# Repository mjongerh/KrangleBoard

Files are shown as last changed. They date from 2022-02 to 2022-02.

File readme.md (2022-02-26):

# Krangle keyboard, a keyboard with way too many buttons
Originally I wanted a keyboard with some additional keys for the purpose of shortcuts in games. 
Then I got inspired by the SpaceCadet and the hyper7 and wanted more buttons, for shortcuts, macros and snippets in coding. 
Unfortunately I couldn't get a keyboard that would suffice my greed, so instead I made my own!
With no experience in building keyboards or 3D-modeling or 3D-printing, I thought I would be a perfect fit for this project.

A lot of insipration was taken from [this](https://github.com/jurassic73/split89/blob/main/readme.md#prepping-the-diodes) example.
It contains a great description of many steps of the assembly process.
I highly recommend to read through it if one intends to builds this or any other 3D-printed handwired keyboard.

A little soundtest for the nerds: https://youtu.be/8HYNmcfg844

## Layout
For the layout I went with a lot of extra buttons for programming and gaming.
Further explaination and information in the [layout](./Layout) section

## Hardware
### 3D modeling the case
In the [STL files](./STLfiles) one can find the stl files for all the parts used.
It was intended to be printed on a creality CR-20, hence the maximum size is 220mmx220mm.
It is definitely not perfect as it was made in SketchUp by a noob.
I would not recommend to us it as a template, but it works as-is and might be helpful as inspiration.
Potential improvements are discussed in the [STL](./STLfiles) section.

### Wiring
Initially the plan was to use 2 microcontrollers, considering the amount of buttons.
However, this has proven to be more difficult than expected.
So instead, I was able to fish a teensy2.0++ from the past and wired everything on a single controller.
In this case it uses the traditional method for wire mapping. (PIN map found in [software](./Software))
Some of the macro wiring does not make sense in this setup, but it was a leftover from a previous attempt.
Considering the amount of space in the keyboard, it should be fine for anyone.
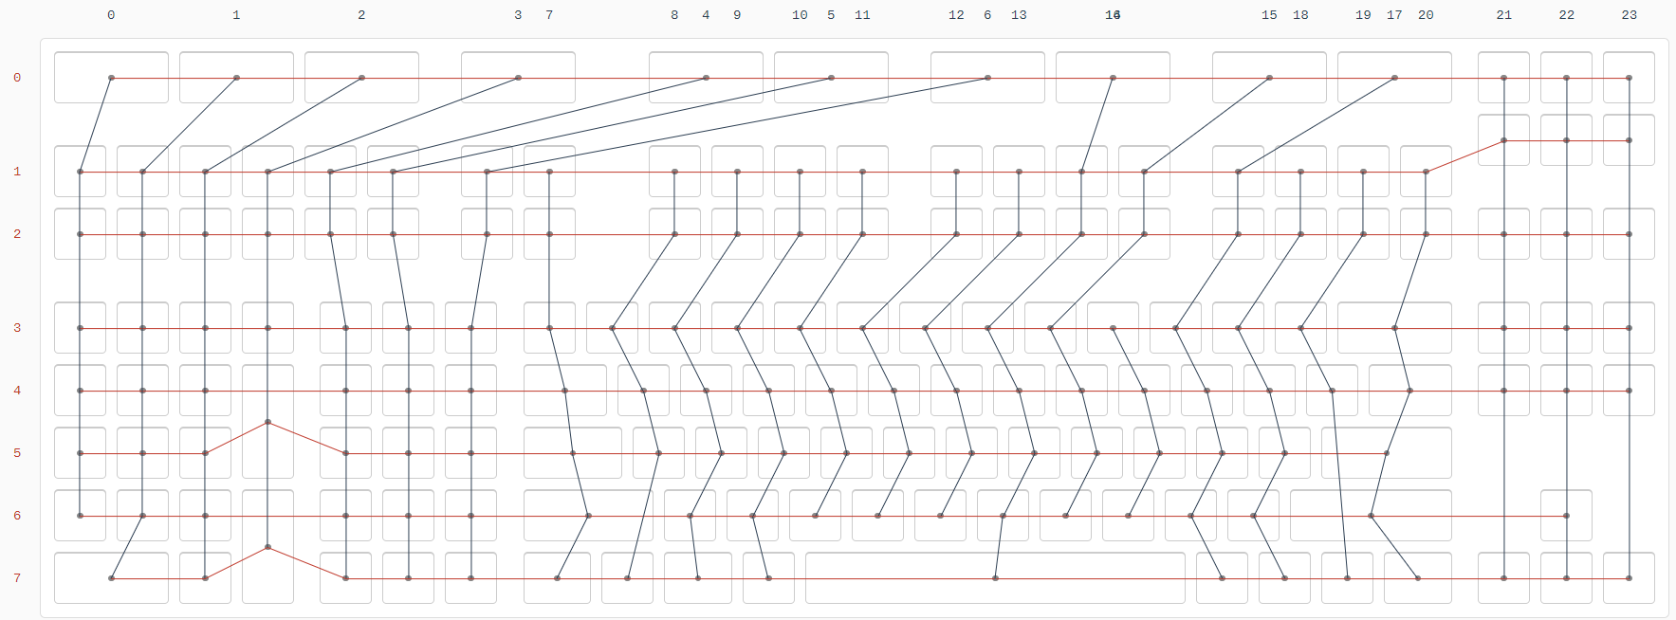
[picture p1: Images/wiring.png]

Note that column 14 is the part that contains only 4 keys in the main part of the board.

Many great tips and tricks can be found externally, for example in [this](https://github.com/jurassic73/split89/blob/main/readme.md#prepping-the-diodes) repo of another 3D printed board.
Out of enthousiasm I designed and 3D-printed a little tool to be used as guidance to bend the pins of the diodes.

### LED circuitry
As the power output of the PINS on any microcontroller are very limited, I used a seperate 5V source for the main set of LEDs.
I cut of one ends of a USB cable and stripped the internal wires.
Only the red(+) and black(-) ones a relevant, so the data wires can be cut off as well.

A typical mothed would be to solder a resistor to each LED and then connect them in parrallel.
This would enable to control each LED individually, which is not on my list of desires and would complicate the connections with the (additional) microcontroller.
However, I am not aware of another benefit of this, apart from a potential short-circuit if one LED somehow breaks.
So I choose to connect all LEDs in parallel with a resistor in series to limit the current.
All negative poles can be soldered in a row and the positive poles likewise.

By connecting these rows together, one ends up with a single point that acts a connection for the negative poles of all LEDs and one for the positive poles.
To control the current to an appropriate level I used ohms law (R=U/I) to calculate a required resistance.
With a maximum of 2mA per LED (obtained experimentally), this would lead to a load resistor of ~15Ω.

To control the current (and therefore the brightness) through the LEDs, I used a MOSFET as 'electronic switch'.
Additionally, two resistors are required as pull-up and pull-down resistor to stabalize the voltage.
This image shows an example setup for the circuit.
Where G,D ans S are the Gate Drain and Source pins of the MOSFET.
PIN indicates the connection to the controlling pin of microcontroller. (PIN map found in [software](./Software))
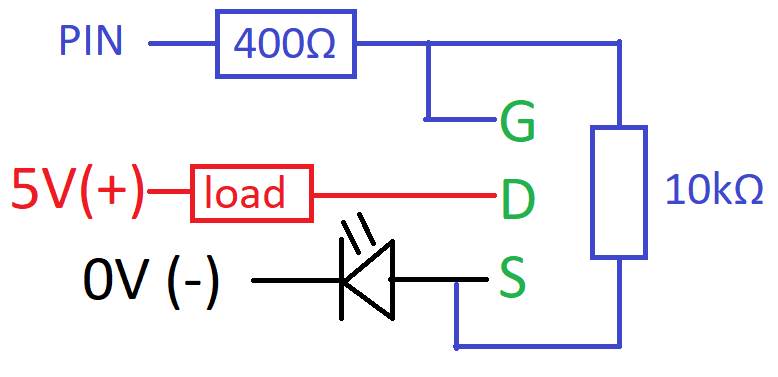
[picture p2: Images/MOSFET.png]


The MOSFET and resistors are placed on the bracket, there is intentionally left some space for this.

The indicator LEDs can be connected directly to the microcontroller, since a single LED don't draw too much current.
This means that a load resistor (2500Ω) should be placed between the microcontroller and the positive end of the LED.
The negative pole of the LED can be connected to the great negative row of the main set of LEDs.
Alternatively it can be connected to the ground pin on the microcontroller.

## Assembly
This section will just show some of the progression of my build.
As a bonus, one will notice how this keyboard got its name.

After putting all the main switchplates and case parts together and pressing all switches in place.
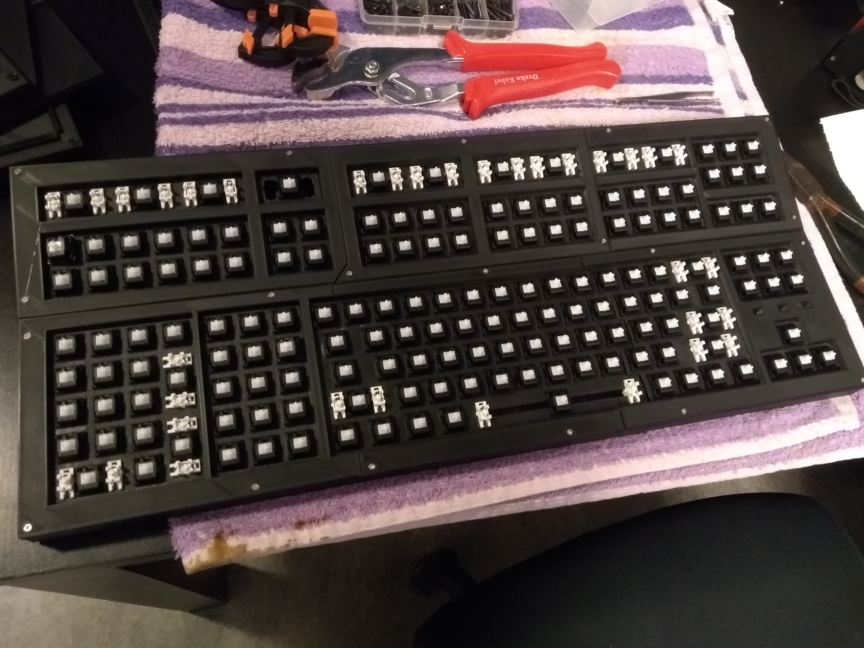
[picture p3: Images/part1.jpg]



Closeup of the wiring and my lackluster soldering skills. 
The bare wires are the pins of the diodes and function as the rows.
The colored wires connect the other pins of the switches and make up the columns.
White and black wires are the + and - of the LEDs.
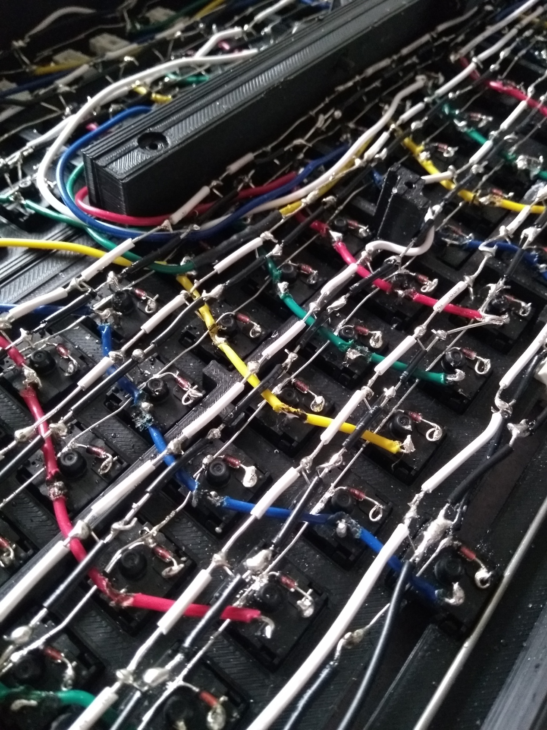
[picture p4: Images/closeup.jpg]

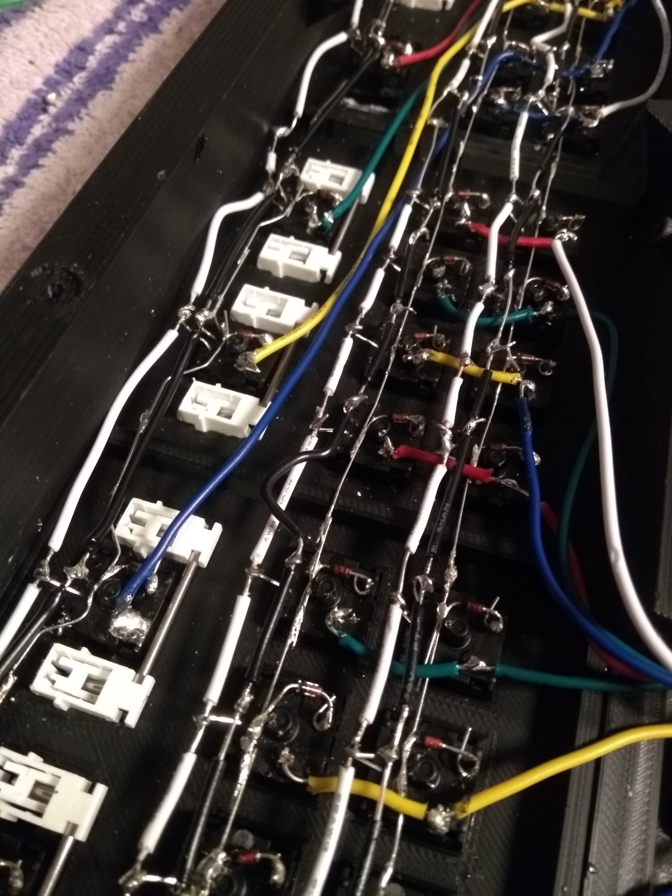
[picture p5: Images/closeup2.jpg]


After connecting the LEDs and testing them.
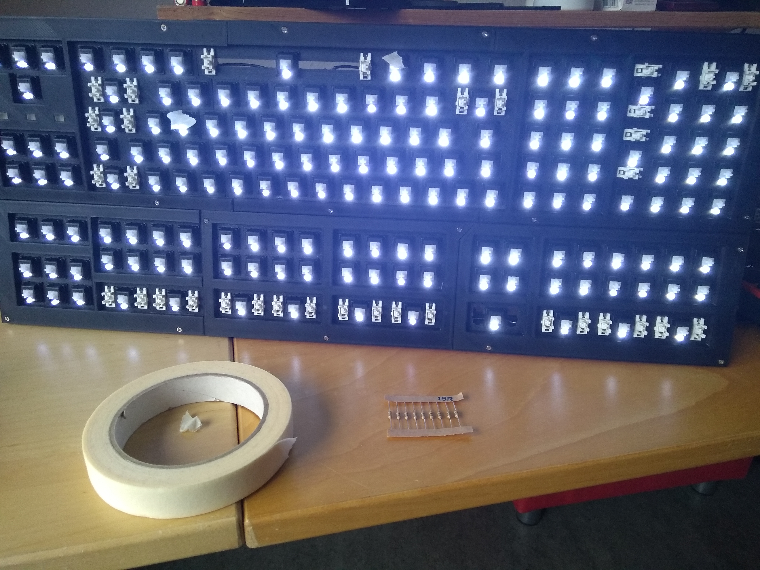
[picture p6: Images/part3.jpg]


Closeup of how the MOSFET is installed
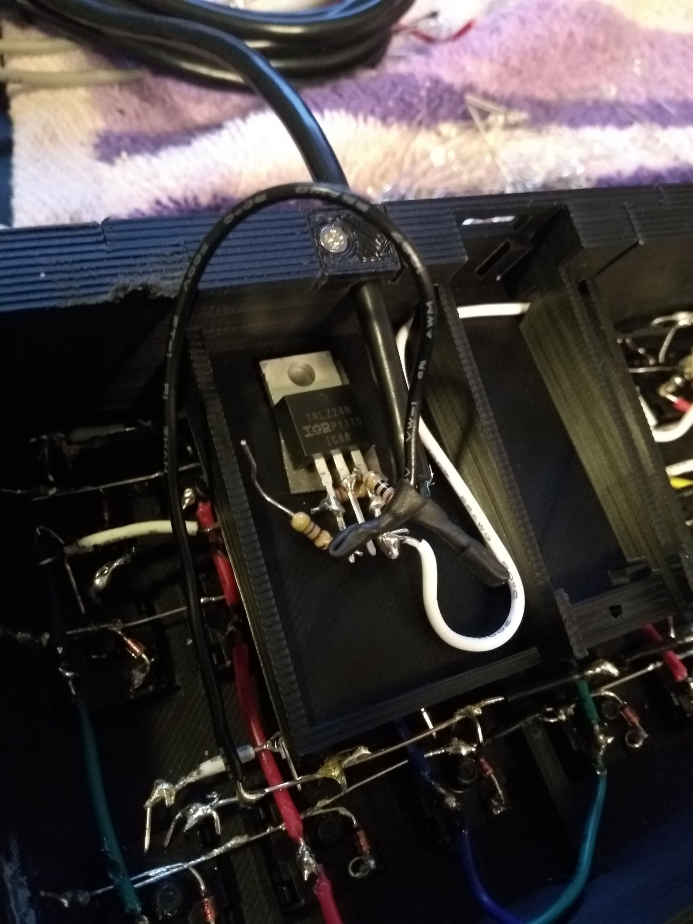
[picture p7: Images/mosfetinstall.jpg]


The beauty in all its glory.
On a daily basis I pray for the wires or one of the connection not to break.
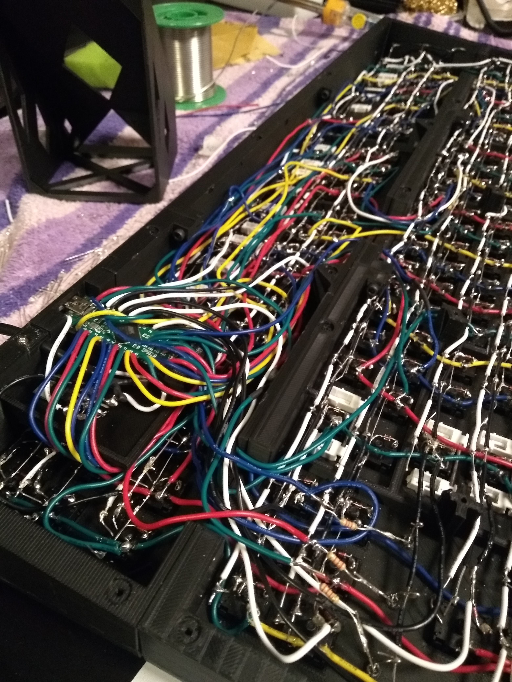
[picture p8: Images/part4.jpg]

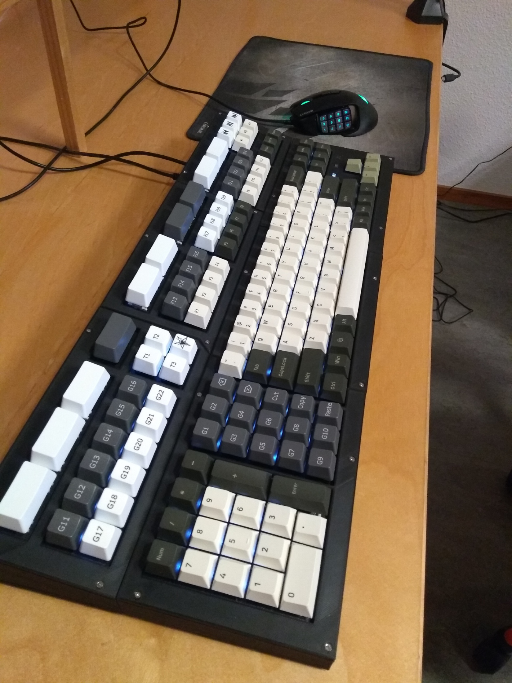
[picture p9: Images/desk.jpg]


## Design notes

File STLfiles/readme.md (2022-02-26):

# STL files
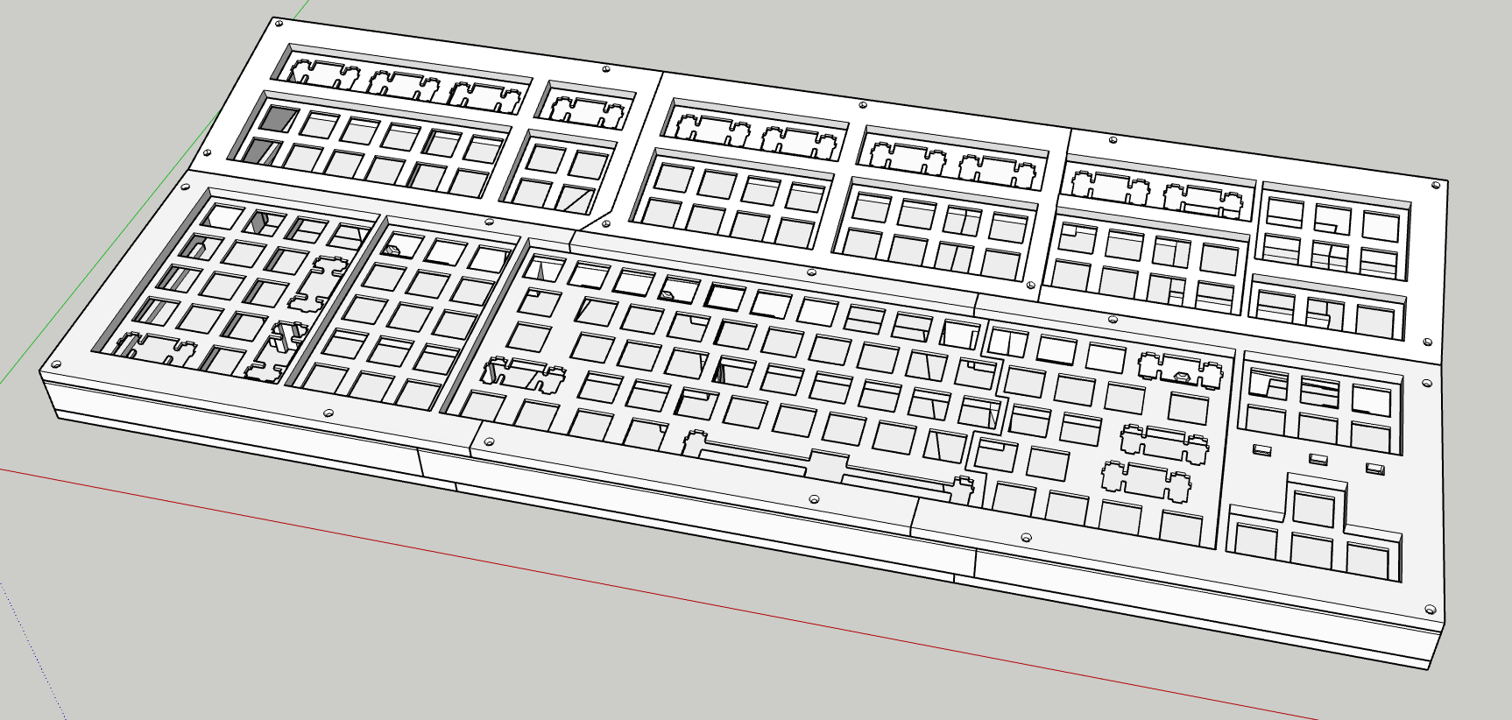
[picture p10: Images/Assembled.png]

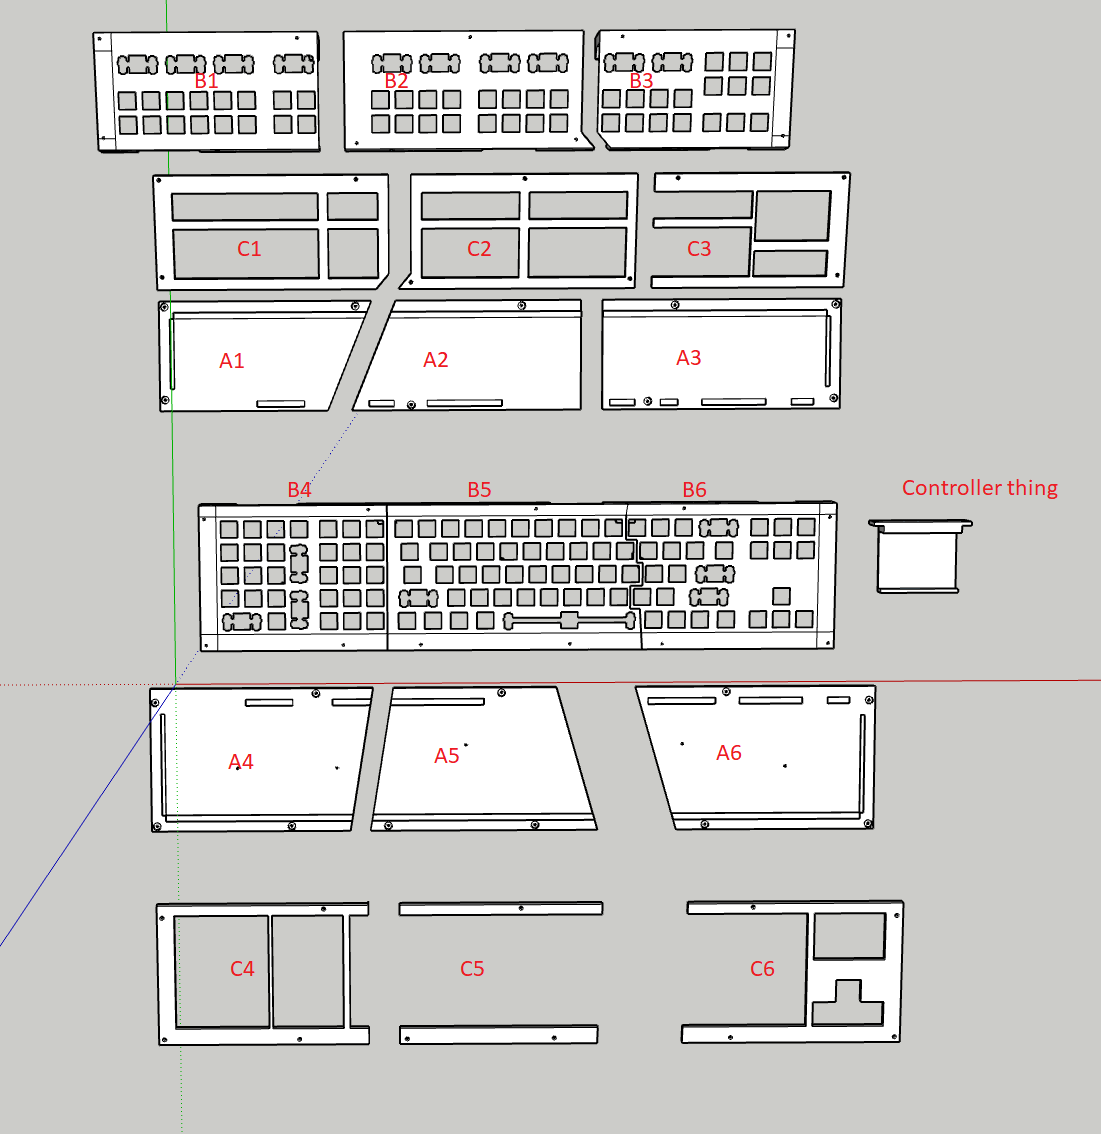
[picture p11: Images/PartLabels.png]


All parts in this [list](./STL_parts) were printed in black PLA on a creality CR-20.
It includes the bracket I made for a teensy2.0++, but a bare version is also there to be adjusted to anything one desires.

Printing settings:
- 0.40mm nozzle
- 0.16mm layer height
- temperature 200C
- infill: hexatriangles 30%

Additionally a very kind friend with a resin printer made some tiny translucent cubes.
These were sanded a bit and placed on top of the indicator LEDs (above the arrow keys).

## furter improvements
Many tiny things are not quite perfect.
Some of which are probably resolved with a better calibrated 3D printer that has linear acceleration correction enabled.
- The seam in the middle of the main part of the keyboard is very sub-optimal. 
 It works, but it is noticeable. 
 The distance between the O and the P is slightly larger than usual and the right part is slightly higher than the left.
 Although, when using the keyboard I have not noticed these issues physically, only visually.
- The connecting part where an M3 bolt and nuts connects the different sections is a bit too small. 
When applying force to screw it tight, two layers of the print slightly came loose.
It is still functional and I don't consider it broken, but it would be nicer if it was a bit stronger.
- without LA correction, the sockets for the stabs didn't print perfectly. 
So quite some post-print surgery had to be performed to make them fit well.
One socket was lost in the process.

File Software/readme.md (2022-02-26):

# Software
As one might expect, I made the software with [QMK](https://qmk.fm).
To edit and compile the software, one can copy the Krangle [folder](./Krangle) and put it in the [keyboards](https://github.com/qmk/qmk_firmware/tree/master/keyboards) folder.
Additional and very extensive instruction can be found in the original [documentation](https://docs.qmk.fm/#/newbs_building_firmware).

The software provided here is made for a teensy2.0++.
It uses an unoptimized PIN layout as follows:
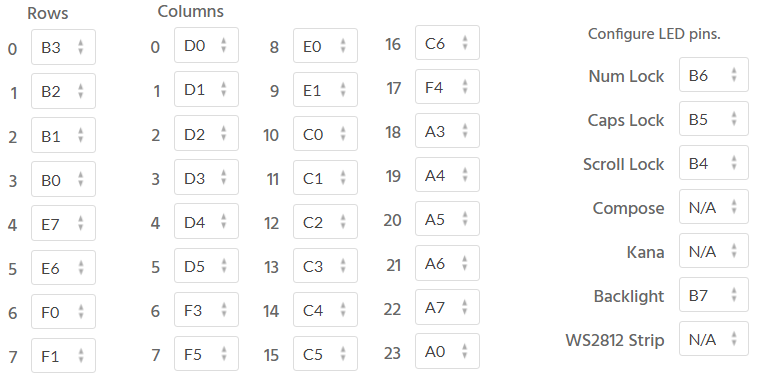
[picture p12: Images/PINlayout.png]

This can also be viewed in the GUI of [kbfirmware](https://kbfirmware.com) by uploading the [JSON file](krangle_kbfirmware.json).

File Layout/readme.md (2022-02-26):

# Layout

For the design of the layout I had the intention of adding the F13-F24 keys ever sice I knew of their existence. 
Previously I had been using a logitech G710+ and was able to map those keys on the macrokeys.
Since they are standard keys, they can be used input keys for any program or game.

Additionally I wanted some shortcut keys on the left of the regular part, with functions such and copy and paste for quick access.
The numpad on the left is because whenever I want to use it, it is for filling in a lot of numbers.
This is significantly more convinient when the right hand can use the arrow keys or the mouse at the same time (i.e. excel or coding).

For coding especially, I had in mind to make some big macro buttons to be used as snippets.
In the default keymap there are some examples put on the first 3 macro keys.
Two of which would a insert block for and image or equation in LATEX.

To fill the void between the numpad and the macro keys, I added G11-G22, with no purpose in mind.
Perhaps some day I'll use it to for scripts, to start certain programs.
T1-T3 are intended by keyboard control, backlight levels, keymap profiles etc.

The [JSON](./keyboard-layout.json) can be viewed in the [layout editor](http://www.keyboard-layout-editor.com/#/).
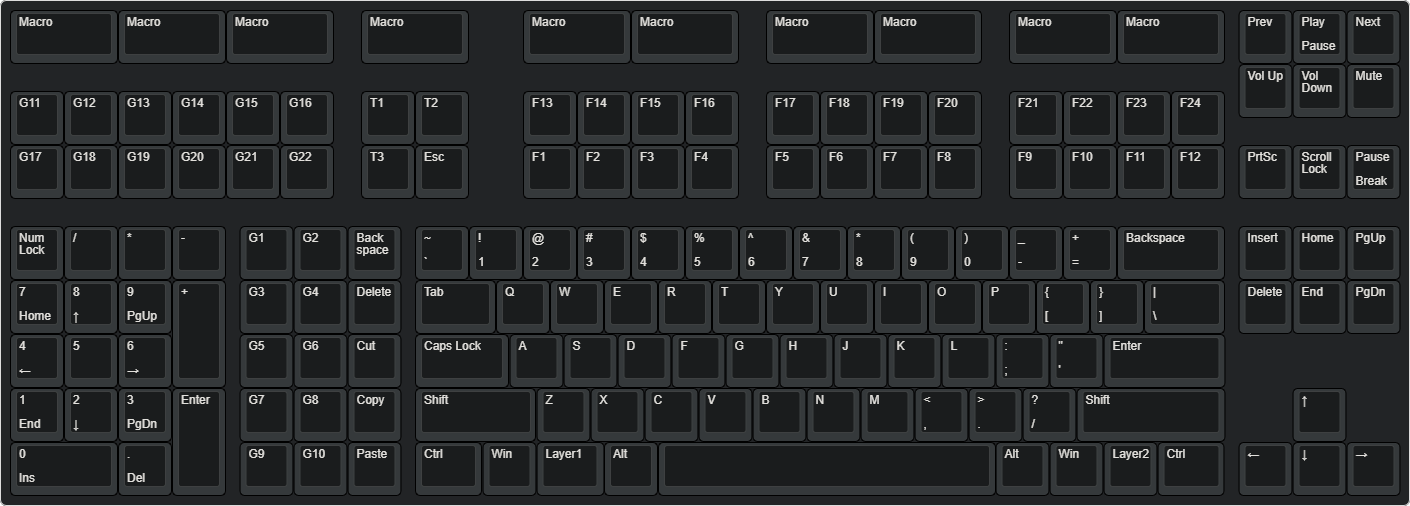
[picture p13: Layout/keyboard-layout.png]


In the default keymap G1-G3 are used as modofier triggers for the special characters used in the [EurKey](https://eurkey.steffen.bruentjen.eu/start.html) layout.
This adds a lot functionality when writing your everyday notes in math and physics.
Full layout options for version 1.2 of EurKey can be found [here](https://eurkey.steffen.bruentjen.eu/download/windows/1.2/eurkey-layout-complete.pdf)

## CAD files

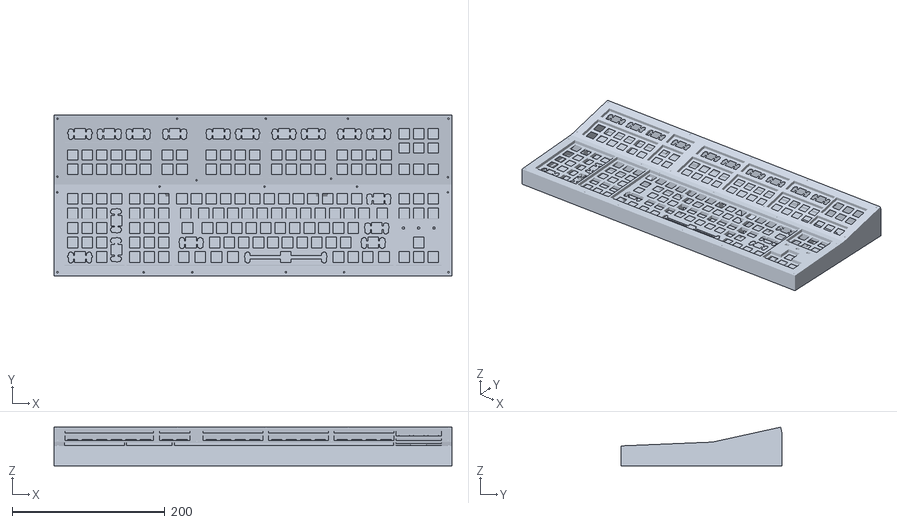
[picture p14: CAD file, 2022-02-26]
STLfiles/KrangleBoard.stl
520.5 x 209.9 x 50.7

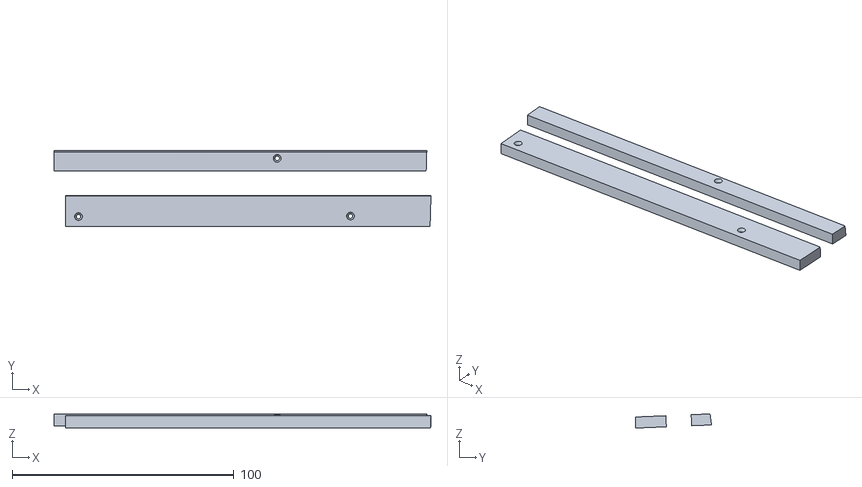
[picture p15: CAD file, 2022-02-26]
STLfiles/STL_parts/TopplateC5.stl
169.8 x 34.3 x 6.40

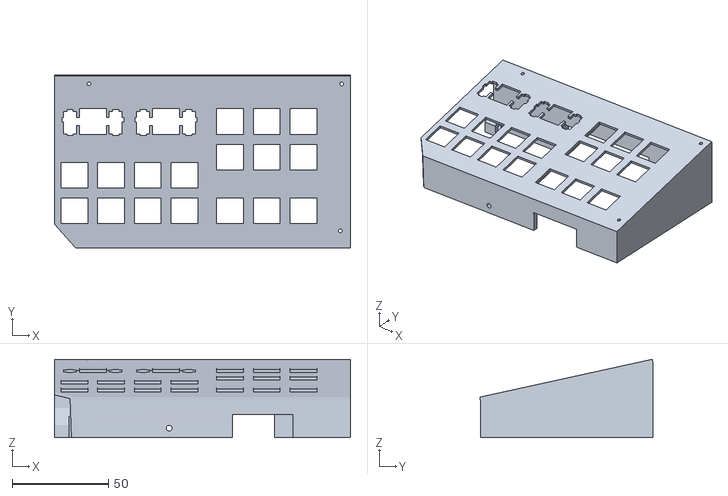
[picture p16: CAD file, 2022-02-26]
STLfiles/STL_parts/SwitchplateB3.stl
154.0 x 89.9 x 40.8

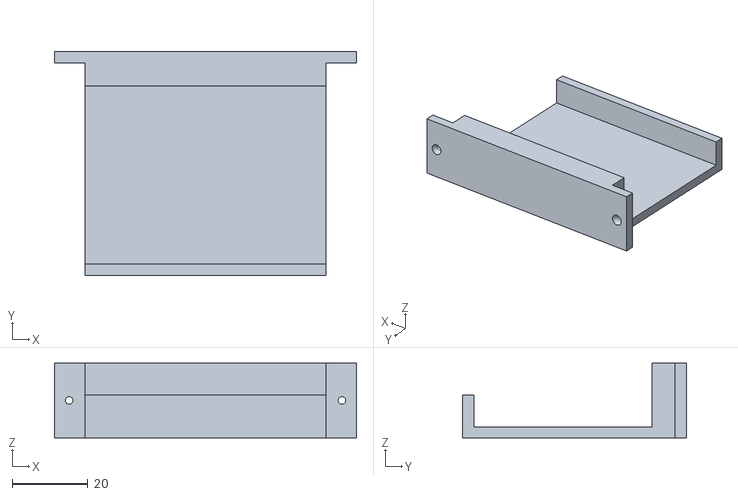
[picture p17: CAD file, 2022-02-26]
STLfiles/STL_parts/ControllerBracketWIP.stl
79.7 x 59.0 x 19.7

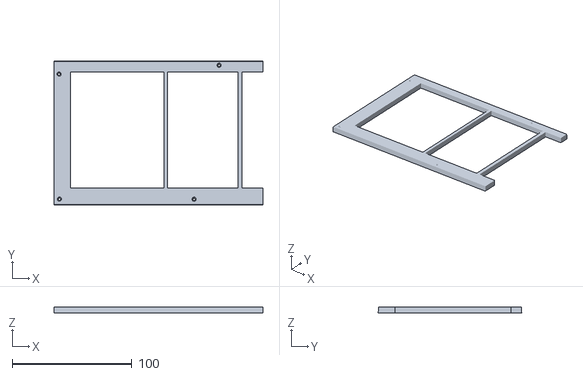
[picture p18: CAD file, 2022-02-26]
STLfiles/STL_parts/TopplateC4.stl
174.9 x 120.2 x 5.00

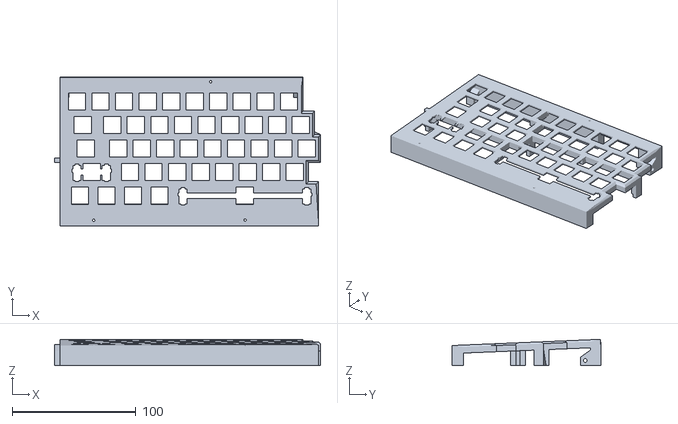
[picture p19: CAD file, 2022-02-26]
STLfiles/STL_parts/SwitchplateB5.stl
215.1 x 120.3 x 21.3

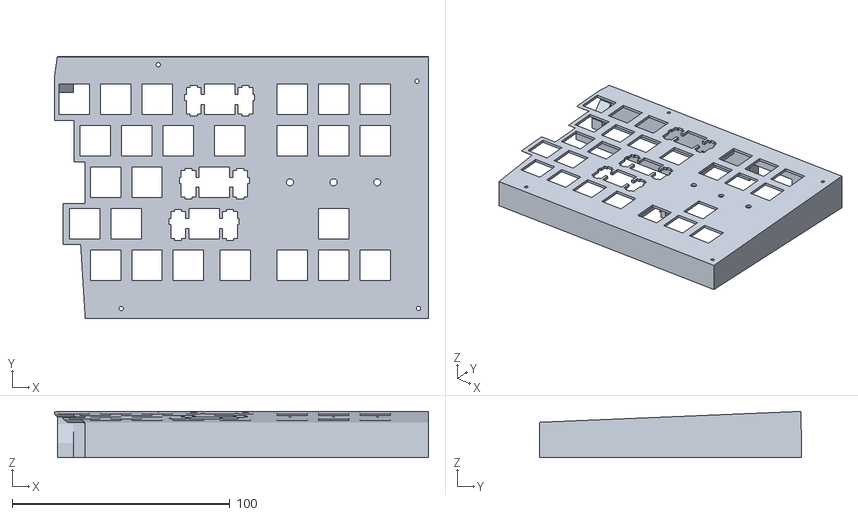
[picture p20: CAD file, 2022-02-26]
STLfiles/STL_parts/SwitchplateB6.stl
171.8 x 120.3 x 21.2

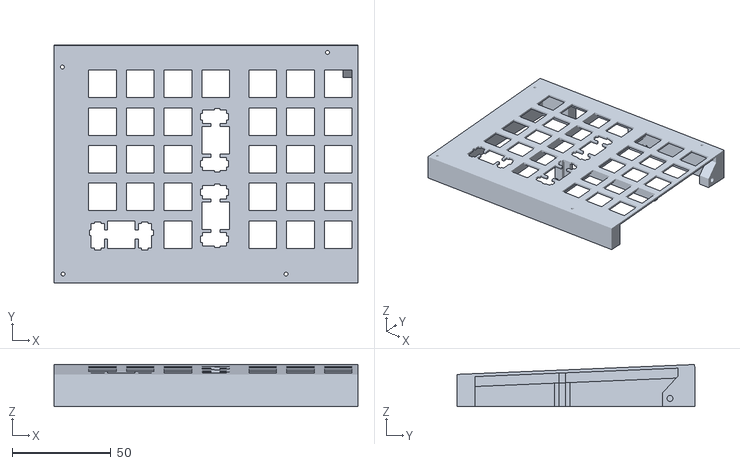
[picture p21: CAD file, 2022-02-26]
STLfiles/STL_parts/SwitchplateB4.stl
153.6 x 120.3 x 21.2

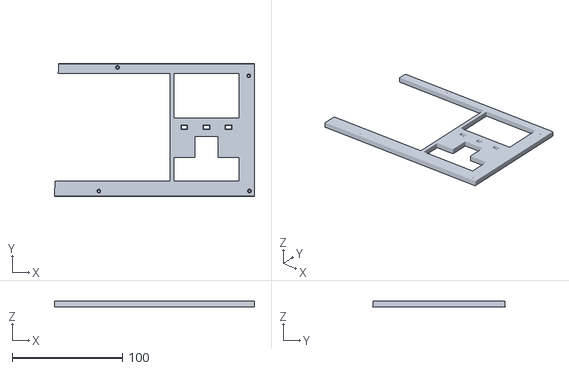
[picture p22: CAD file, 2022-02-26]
STLfiles/STL_parts/TopplateC6.stl
181.3 x 120.2 x 5.00

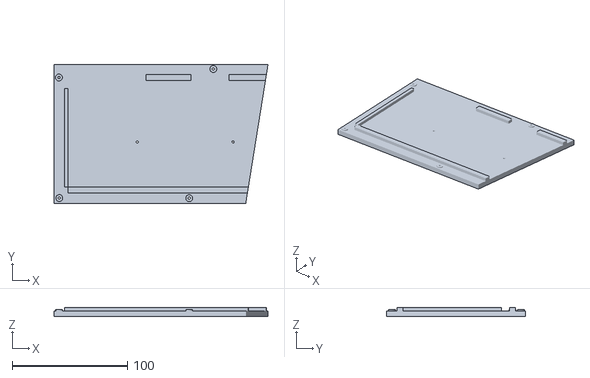
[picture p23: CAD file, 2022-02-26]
STLfiles/STL_parts/BaseplateA4.stl
185.6 x 120.2 x 8.00

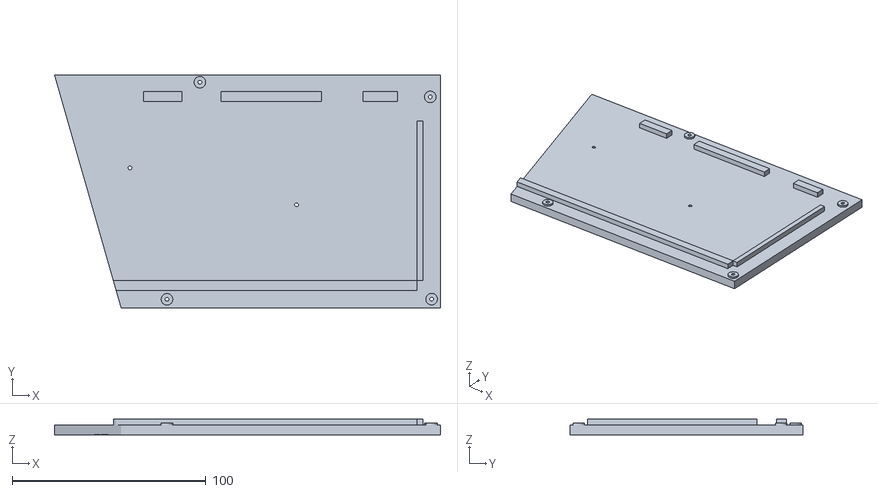
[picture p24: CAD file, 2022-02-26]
STLfiles/STL_parts/BaseplateA6.stl
199.2 x 120.2 x 8.00

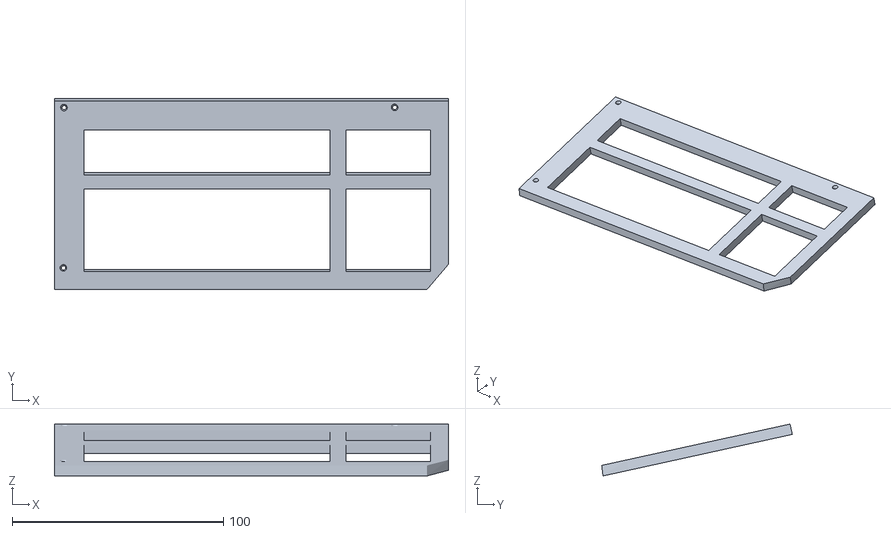
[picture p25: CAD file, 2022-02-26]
STLfiles/STL_parts/TopplateC1.stl
186.3 x 90.2 x 24.5

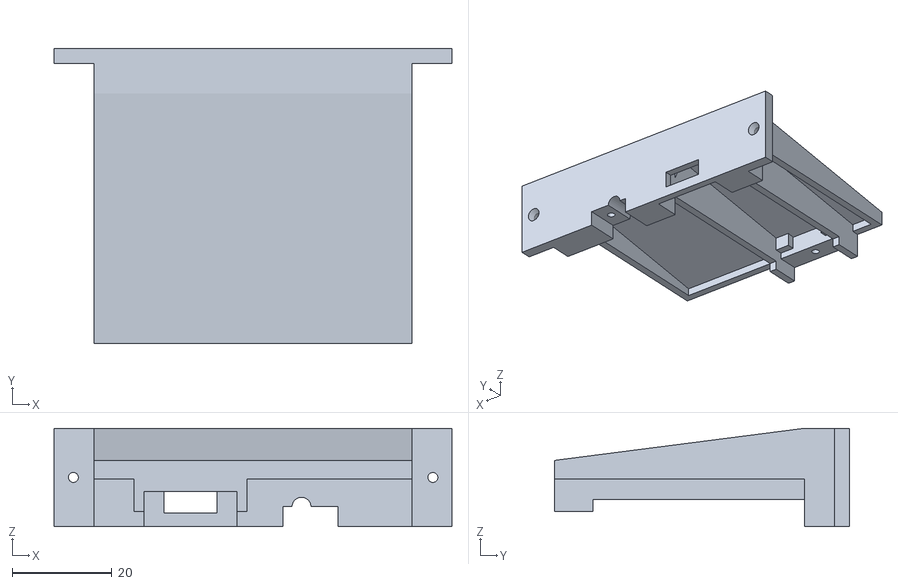
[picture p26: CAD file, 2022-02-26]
STLfiles/STL_parts/Bracket_teensy2++.stl
79.7 x 59.0 x 19.7

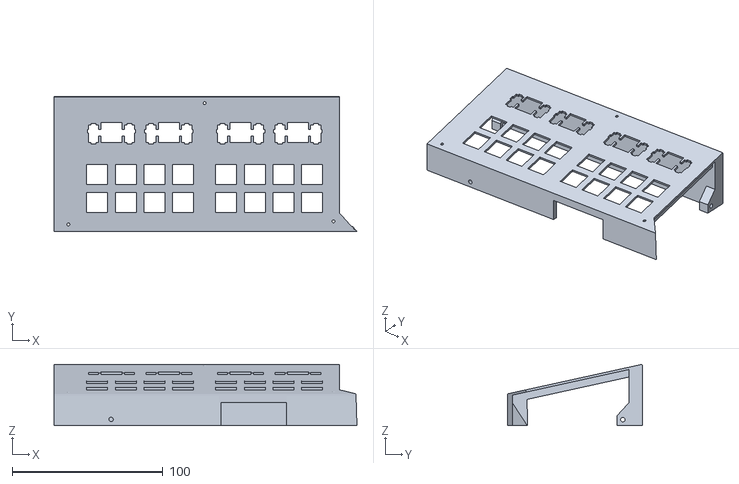
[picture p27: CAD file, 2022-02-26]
STLfiles/STL_parts/SwitchplateB2.stl
201.3 x 89.9 x 40.8

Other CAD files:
STLfiles/STL_parts/Bracket_teensy2++_add1.stl
STLfiles/STL_parts/BaseplateA5.stl
STLfiles/STL_parts/Bracket_teensy2++_add2.stl
STLfiles/STL_parts/TopplateC3.stl
STLfiles/STL_parts/BaseplateA1.stl
STLfiles/STL_parts/BaseplateA2.stl
STLfiles/STL_parts/BaseplateA3.stl
STLfiles/STL_parts/SwitchplateB1.stl
STLfiles/STL_parts/TopplateC2.stl

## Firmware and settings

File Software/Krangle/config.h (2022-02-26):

#ifndef CONFIG_H
#define CONFIG_H

#include "config_common.h"

/* USB Device descriptor parameter */
#define VENDOR_ID       0xFEED
#define PRODUCT_ID      0x6060
#define DEVICE_VER      0x0001
#define MANUFACTURER    qmkbuilder
#define PRODUCT         KrangleKeyboard
#define DESCRIPTION     Keyboard

/* key matrix size */
#define MATRIX_ROWS 8
#define MATRIX_COLS 24

/* key matrix pins */
#define MATRIX_ROW_PINS { B3, B2, B1, B0, E7, E6, F0, F1 }
#define MATRIX_COL_PINS { D0, D1, D2, D3, D4, D5, F3, F5, E0, E1, C0, C1, C2, C3, C4, C5, C6, F4, A3, A4, A5, A6, A7, A0 }
#define UNUSED_PINS

/* COL2ROW or ROW2COL */
#define DIODE_DIRECTION COL2ROW

/* number of backlight levels */
#define BACKLIGHT_PIN B7
#ifdef BACKLIGHT_PIN
#define BACKLIGHT_LEVELS 3
#endif

/* Set 0 if debouncing isn't needed */
#define DEBOUNCING_DELAY 5

/* Mechanical locking support. Use KC_LCAP, KC_LNUM or KC_LSCR instead in keymap */
#define LOCKING_SUPPORT_ENABLE

/* Locking resynchronize hack */
#define LOCKING_RESYNC_ENABLE

/* key combination for command */
#define IS_COMMAND() ( \
    keyboard_report->mods == (MOD_BIT(KC_LSHIFT) | MOD_BIT(KC_RSHIFT)) \
)

/* prevent stuck modifiers */
#define PREVENT_STUCK_MODIFIERS

// delay in between tap_code(<kc>) commands for macros
#define TAP_CODE_DELAY 10

#ifdef RGB_DI_PIN
#define RGBLIGHT_ANIMATIONS
#define RGBLED_NUM 0
#define RGBLIGHT_HUE_STEP 8
#define RGBLIGHT_SAT_STEP 8
#define RGBLIGHT_VAL_STEP 8
#endif

#endif

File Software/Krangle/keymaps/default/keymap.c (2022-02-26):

#include "krangle.h"

enum custom_keycodes {
	QMKBEST = SAFE_RANGE,
	MMACRO_0,
	MMACRO_1,
	MMACRO_2,
	MMACRO_3,
	MMACRO_4,
	MMACRO_5,
	MMACRO_6,
	MMACRO_7,
	MMACRO_8,
	MMACRO_9,
	GMACRO_1,
	GMACRO_2,
	GMACRO_3,
	GMACRO_4,
	GMACRO_5,
	GMACRO_6,
	GMACRO_7,
	GMACRO_8,
	GMACRO_9,
	GMACRO_10,
	GMACRO_11,
	GMACRO_12,
	GMACRO_13,
	GMACRO_14,
	GMACRO_15,
	GMACRO_16,
	GMACRO_17,
	GMACRO_18,
	GMACRO_19,
	GMACRO_20,
	GMACRO_21,
	GMACRO_22,
};


bool process_record_user(uint16_t keycode, keyrecord_t* record) {

	switch (keycode) {
	case MMACRO_0:
		if (record->event.pressed) {
			SEND_STRING("Your favorite piece of text");
			return false;
		}
		else {}
		break;
	case MMACRO_1:
		if (record->event.pressed) {
			SEND_STRING("\\begin{figure}[h!]" SS_TAP(X_ENT));
			SEND_STRING(SS_TAP(X_TAB) "\\centering" SS_TAP(X_SPC) SS_DELAY(20) SS_TAP(X_ENT));
			SEND_STRING("\\includegraphics[width=0.75\\textwidth]{FILENAME}" SS_TAP(X_SPC) SS_DELAY(20) SS_TAP(X_ENT));
			SEND_STRING("\\caption{CaptionText}" SS_TAP(X_SPC) SS_DELAY(20) SS_TAP(X_ENT));
			SEND_STRING("\\label{fig:}" SS_TAP(X_SPC) SS_DELAY(20) SS_TAP(X_ENT));
			SEND_STRING(SS_TAP(X_BSPC) "\\end{figure}" SS_TAP(X_SPC) SS_DELAY(20) SS_TAP(X_ENT));
			return false;
		}
		else {}
		break;
	case MMACRO_2:
		if (record->event.pressed) {
			SEND_STRING("\\begin{equation}" SS_TAP(X_SPC) SS_DELAY(20) SS_TAP(X_ENT));
			SEND_STRING("" SS_TAP(X_TAB) SS_DELAY(20) SS_TAP(X_ENT));
			SEND_STRING("\\label{eq:}" SS_TAP(X_SPC) SS_DELAY(20) SS_TAP(X_ENT));
			SEND_STRING(SS_TAP(X_BSPC) "\\end{equation}" SS_TAP(X_SPC) SS_DELAY(20) SS_TAP(X_ENT));
			return false;
		}
		else {}
		break;
	case GMACRO_1:
		if (record->event.pressed) {
			register_code(KC_RALT);
			tap_code(KC_M);
			unregister_code(KC_RALT);
			return false;
		}
		else {}
		break;
	case GMACRO_2:
		if (record->event.pressed) {
			register_code(KC_RALT);
			tap_code(KC_MINS);
			unregister_code(KC_RALT);
			return false;
		}
		else {}
		break;
	case GMACRO_3:
		if (record->event.pressed) {
			register_code(KC_LSFT);
			register_code(KC_RALT);
			tap_code(KC_M);
			unregister_code(KC_RALT);
			unregister_code(KC_LSFT);
			return false;
		}
		else {}
		break;
	}
	return true;
}

const uint16_t PROGMEM keymaps[][MATRIX_ROWS][MATRIX_COLS] = {

	KEYMAP(
		MMACRO_0, MMACRO_1, MMACRO_2, KC_4, KC_5, KC_6, KC_7, KC_8, KC_9, KC_0, KC_MPRV, KC_MPLY, KC_MNXT,
		KC_1, KC_2, KC_3, KC_4, KC_5, KC_6, KC_1, KC_2, KC_F13, KC_F14, KC_F15, KC_F16, KC_F17, KC_F18, KC_F19, KC_F20, KC_F21, KC_F22, KC_F23, KC_F24, KC_VOLD, KC_VOLU, KC_MUTE,
		KC_7, KC_8, KC_9, KC_0, KC_1, KC_2, BL_STEP, KC_ESC, KC_F1, KC_F2, KC_F3, KC_F4, KC_F5, KC_F6, KC_F7, KC_F8, KC_F9, KC_F10, KC_F11, KC_F12, KC_PSCR, KC_SLCK, KC_PAUS,
		KC_NLCK, KC_PSLS, KC_PAST, KC_PMNS, GMACRO_1, GMACRO_2, KC_BSPC, KC_GRV, KC_1, KC_2, KC_3, KC_4, KC_5, KC_6, KC_7, KC_8, KC_9, KC_0, KC_MINS, KC_EQL, KC_BSPC, KC_INS, KC_HOME, KC_PGUP,
		KC_P7, KC_P8, KC_P9, GMACRO_3, KC_4, KC_DEL, KC_TAB, KC_Q, KC_W, KC_E, KC_R, KC_T, KC_Y, KC_U, KC_I, KC_O, KC_P, KC_LBRC, KC_RBRC, KC_BSLS, KC_DEL, KC_END, KC_PGDN,
		KC_P4, KC_P5, KC_P6, KC_PPLS, KC_5, KC_6, LCTL(KC_X), KC_CAPS, KC_A, KC_S, KC_D, KC_F, KC_G, KC_H, KC_J, KC_K, KC_L, KC_SCLN, KC_QUOT, KC_ENT,
		KC_P1, KC_P2, KC_P3, KC_7, KC_8, LCTL(KC_C), KC_LSFT, KC_Z, KC_X, KC_C, KC_V, KC_B, KC_N, KC_M, KC_COMM, KC_DOT, KC_SLSH, KC_LSFT, KC_UP,
		KC_P0, KC_PDOT, KC_PENT, KC_9, KC_0, LCTL(KC_V), KC_LCTL, KC_LGUI, MO(1), KC_LALT, KC_SPC, KC_RALT, KC_RGUI, MO(2), KC_RCTL, KC_LEFT, KC_DOWN, KC_RGHT),

	KEYMAP(
		KC_TRNS, KC_TRNS, KC_TRNS, KC_TRNS, KC_TRNS, KC_TRNS, KC_TRNS, KC_TRNS, KC_TRNS, KC_TRNS, KC_TRNS, KC_TRNS, KC_TRNS,
		KC_TRNS, KC_TRNS, KC_TRNS, KC_TRNS, KC_TRNS, KC_TRNS, KC_TRNS, KC_TRNS, KC_TRNS, KC_TRNS, KC_TRNS, KC_TRNS, KC_TRNS, KC_TRNS, KC_TRNS, KC_TRNS, KC_TRNS, KC_TRNS, KC_TRNS, KC_TRNS, KC_TRNS, KC_TRNS, KC_TRNS,
		KC_TRNS, KC_TRNS, KC_TRNS, KC_TRNS, KC_TRNS, KC_TRNS, KC_TRNS, KC_TRNS, KC_TRNS, KC_TRNS, KC_TRNS, KC_TRNS, KC_TRNS, KC_TRNS, KC_TRNS, KC_TRNS, KC_TRNS, KC_TRNS, KC_TRNS, KC_TRNS, KC_TRNS, KC_TRNS, KC_TRNS,
		KC_TRNS, KC_TRNS, KC_TRNS, KC_TRNS, KC_TRNS, KC_TRNS, KC_TRNS, KC_TRNS, KC_TRNS, KC_TRNS, KC_TRNS, KC_TRNS, KC_TRNS, KC_TRNS, KC_TRNS, KC_TRNS, KC_TRNS, KC_TRNS, KC_TRNS, KC_TRNS, KC_TRNS, KC_TRNS, KC_TRNS, KC_TRNS,
		KC_TRNS, KC_TRNS, KC_TRNS, KC_TRNS, KC_TRNS, KC_TRNS, KC_TRNS, KC_TRNS, KC_TRNS, KC_TRNS, KC_TRNS, KC_TRNS, KC_TRNS, KC_TRNS, KC_TRNS, KC_TRNS, KC_TRNS, KC_TRNS, KC_TRNS, KC_TRNS, KC_TRNS, KC_TRNS, KC_TRNS,
		KC_TRNS, KC_TRNS, KC_TRNS, KC_TRNS, KC_TRNS, KC_TRNS, KC_TRNS, KC_TRNS, KC_TRNS, KC_TRNS, KC_TRNS, KC_TRNS, KC_TRNS, KC_TRNS, KC_TRNS, KC_TRNS, KC_TRNS, KC_TRNS, KC_TRNS, KC_TRNS,
		KC_TRNS, KC_TRNS, KC_TRNS, KC_TRNS, KC_TRNS, KC_TRNS, KC_TRNS, KC_TRNS, KC_TRNS, KC_TRNS, KC_TRNS, KC_TRNS, KC_TRNS, KC_TRNS, KC_TRNS, KC_TRNS, KC_TRNS, KC_TRNS, KC_TRNS,
		KC_TRNS, KC_TRNS, KC_TRNS, KC_TRNS, KC_TRNS, KC_TRNS, KC_TRNS, KC_TRNS, KC_TRNS, KC_TRNS, KC_TRNS, KC_TRNS, KC_TRNS, KC_TRNS, KC_TRNS, KC_TRNS, KC_TRNS, KC_TRNS),

	KEYMAP(
		KC_TRNS, KC_TRNS, KC_TRNS, KC_TRNS, KC_TRNS, KC_TRNS, KC_TRNS, KC_TRNS, KC_TRNS, KC_TRNS, KC_TRNS, KC_TRNS, KC_TRNS,
		KC_TRNS, KC_TRNS, KC_TRNS, KC_TRNS, KC_TRNS, KC_TRNS, KC_TRNS, KC_TRNS, KC_TRNS, KC_TRNS, KC_TRNS, KC_TRNS, KC_TRNS, KC_TRNS, KC_TRNS, KC_TRNS, KC_TRNS, KC_TRNS, KC_TRNS, KC_TRNS, KC_TRNS, KC_TRNS, KC_TRNS,
		KC_TRNS, KC_TRNS, KC_TRNS, KC_TRNS, KC_TRNS, KC_TRNS, KC_TRNS, KC_TRNS, KC_TRNS, KC_TRNS, KC_TRNS, KC_TRNS, KC_TRNS, KC_TRNS, KC_TRNS, KC_TRNS, KC_TRNS, KC_TRNS, KC_TRNS, KC_TRNS, KC_TRNS, KC_TRNS, KC_TRNS,
		KC_TRNS, KC_TRNS, KC_TRNS, KC_TRNS, KC_TRNS, KC_TRNS, KC_TRNS, KC_TRNS, KC_TRNS, KC_TRNS, KC_TRNS, KC_TRNS, KC_TRNS, KC_TRNS, KC_TRNS, KC_TRNS, KC_TRNS, KC_TRNS, KC_TRNS, KC_TRNS, KC_TRNS, KC_TRNS, KC_TRNS, KC_TRNS,
		KC_TRNS, KC_TRNS, KC_TRNS, KC_TRNS, KC_TRNS, KC_TRNS, KC_TRNS, KC_TRNS, KC_TRNS, KC_TRNS, KC_TRNS, KC_TRNS, KC_TRNS, KC_TRNS, KC_TRNS, KC_TRNS, KC_TRNS, KC_TRNS, KC_TRNS, KC_TRNS, KC_TRNS, KC_TRNS, KC_TRNS,
		KC_TRNS, KC_TRNS, KC_TRNS, KC_TRNS, KC_TRNS, KC_TRNS, KC_TRNS, KC_TRNS, KC_TRNS, KC_TRNS, KC_TRNS, KC_TRNS, KC_TRNS, KC_TRNS, KC_TRNS, KC_TRNS, KC_TRNS, KC_TRNS, KC_TRNS, KC_TRNS,
		KC_TRNS, KC_TRNS, KC_TRNS, KC_TRNS, KC_TRNS, KC_TRNS, KC_TRNS, KC_TRNS, KC_TRNS, KC_TRNS, KC_TRNS, KC_TRNS, KC_TRNS, KC_TRNS, KC_TRNS, KC_TRNS, KC_TRNS, KC_TRNS, KC_TRNS,
		KC_TRNS, KC_TRNS, KC_TRNS, KC_TRNS, KC_TRNS, KC_TRNS, KC_TRNS, KC_TRNS, KC_TRNS, KC_TRNS, KC_TRNS, KC_TRNS, KC_TRNS, KC_TRNS, KC_TRNS, KC_TRNS, KC_TRNS, KC_TRNS),

};

void matrix_init_user(void) {
}

void matrix_scan_user(void) {
}
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
